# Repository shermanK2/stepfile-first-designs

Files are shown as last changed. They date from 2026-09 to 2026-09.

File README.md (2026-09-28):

# First designs — STEP files

Wing and tail designs for small RC aircraft, exported as STEP files for manufacturing.
Each design iteration is kept in its own folder so earlier versions stay available and
comparable.

## Layout

```
<aircraft>/
├── README.md                    aircraft reference data (published specs, measurements)
└── v<N>-<YYYY-MM-DD>/           one folder per design iteration
    ├── README.md                design notes: parameters, dimensions, results, status
    ├── wing/                    main wing
    ├── tail/                    horizontal tail (hstab) and fin (vstab)
    └── assembly/                full aircraft, for fit checks only — not for cutting
templates/
└── design-notes.md              copy this into each new iteration folder
```

## Iterations

| Aircraft | Version | Date | Summary | Status |
|---|---|---|---|---|
| [Kavan Beta 1400](kavan-beta-1400/) | [v1](kavan-beta-1400/v1-2026-09-28/) | 2026-09-28 | Trapezoidal wing (AR 8, taper 0.6, 3° dihedral), conventional tail | Designed, not built |

## Conventions

- **Units:** every STEP file is in **millimetres**.
- **File names:** `<part>_mm.step`, e.g. `wing_mm.step`, `hstab_mm.step`, `fin_mm.step`.
- **Versions are never edited after they are sent to manufacturing.** A change means a new
  folder (`v2-…`), not an overwrite. Small fixes before anything is sent can stay in the
  same version; note them in its README.
- **Coordinates:** x = chordwise (aft positive), y = spanwise, z = up. Separate part files
  are in the part's own frame; the assembly file is in aircraft coordinates.

## Adding a new iteration

1. Create `<aircraft>/v<N>-<YYYY-MM-DD>/` with `wing/`, `tail/` and `assembly/` inside.
2. Copy the new STEP files in. Check each one opens at the expected size in mm.
3. Copy [`templates/design-notes.md`](templates/design-notes.md) to the new folder as
   `README.md` and fill it in, including **what changed since the previous version**.
4. Add a row to the **Iterations** table above.
5. Commit with a message like `Kavan Beta 1400 v2: <what changed>`.

## Tooling

The designs are generated with AeroForge (IDEAL Lab, ETH Zürich). The design scripts
live with the lab's AeroForge repository and are not included here.

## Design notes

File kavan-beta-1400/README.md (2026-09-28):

# Kavan Beta 1400

EPO-foam trainer / motor glider with aileron, elevator, rudder and motor control. New
wings and tails are designed to fit its existing fuselage.

## Published specifications

| | Value |
|---|---|
| Wingspan | 1400 mm |
| Length | 966 mm |
| Wing area | 24.5 dm² (0.245 m²) → aspect ratio 8.0, mean chord 175 mm |
| Flying weight | 700–770 g → wing loading ≈ 2.9–3.1 kg/m² |
| Motor / prop | C2814-1400 brushless, 7×6" folding prop |
| ESC | 20 A |
| Battery | 3S 11.1 V LiPo, 1600 mAh (up to 2200 mAh) |
| Servos | 4 × GO-09 (9 g) |

Sources: [kavanrc.com](https://www.kavanrc.com/en/item/kavan-beta-1400-rtf-red-151588),
[air-rc.com](https://www.air-rc.com/aircraft/kavan_beta-1400_kav02-8085).

## Not published — to measure on the real fuselage

| | Value |
|---|---|
| Fuselage max width / height | _to measure_ |
| Nose → wing root leading edge | _to measure_ |
| Nose → tailplane root leading edge | _to measure_ |
| Nose → fin root leading edge | _to measure_ |
| Wing mount / saddle shape | _to measure_ |
| Stock CG position | _to measure_ |

Fill these in once measured; later versions should use them instead of placeholders.

## Versions

| Version | Date | Summary |
|---|---|---|
| [v1](v1-2026-09-28/) | 2026-09-28 | First trapezoidal wing and conventional tail |

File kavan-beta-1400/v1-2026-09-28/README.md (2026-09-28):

# Kavan Beta 1400 — v1 (2026-09-28)

First trapezoidal wing and conventional tail designed around the Kavan Beta 1400 fuselage.

**Status:** designed, not yet built or flown.
**Changes from previous version:** none — first version.

## Files

| File | Part | Size (x × y × z, mm) |
|---|---|---|
| [`wing/wing_mm.step`](wing/wing_mm.step) | Main wing, one piece tip to tip | 218.8 × 1400.0 × 56.3 |
| [`tail/hstab_mm.step`](tail/hstab_mm.step) | Horizontal tail | 131.3 × 420.0 × 15.8 |
| [`tail/fin_mm.step`](tail/fin_mm.step) | Fin (exported lying flat, height along y) | 168.9 × 190.0 × 20.3 |
| [`assembly/aircraft_fitcheck_mm.step`](assembly/aircraft_fitcheck_mm.step) | Full aircraft — fit check only | 1034.7 × 1400.0 × 303.5 |

All files are in millimetres.

## Design parameters

| Part | Span | Aspect ratio | Taper | Thickness | Sweep | Dihedral | Airfoil |
|---|---|---|---|---|---|---|---|
| Wing | 1400 mm | 8.0 | 0.6 | 12 % | 0° | 3° | NACA 2412 |
| Horizontal tail | 420 mm | 4.0 | 0.6 | 10 % | 0° | 0° | NACA 0012 |
| Fin | 190 mm (height) | 1.5 | 0.5 | 10 % | 0° | — | NACA 0012 |

## Derived dimensions

| | Wing | Horizontal tail | Fin |
|---|---|---|---|
| Area | 0.2450 m² | 0.0441 m² | 0.0241 m² |
| Mean chord | 175.0 mm | 105.0 mm | 126.7 mm |
| Root chord | 218.8 mm | 131.3 mm | 168.9 mm |
| Tip chord | 131.3 mm | 78.8 mm | 84.4 mm |
| Mean aerodynamic chord (MAC) | 178.6 mm | | |

Tail volume coefficients (tail arm 599 mm): horizontal **0.62**, vertical **0.042** —
both in the usual trainer range (0.45–0.65 and 0.035–0.05).

## Fuselage and placement used

| | Value | Source |
|---|---|---|
| Fuselage length | 966 mm | Published |
| Fuselage width × height | 150 × 140 mm | **Placeholder** |
| Wing ¼-root-chord position | 30 % of length (290 mm from nose) | **Placeholder** |
| Tail ¼-root-chord position | 92 % of length (889 mm from nose) | **Placeholder** |

The fit-check assembly uses these placeholders, so it is approximate until they are measured.

## Predicted performance (AeroForge handbook models)

| | Value | Notes |
|---|---|---|
| Flying weight used | 0.737 kg | Tuned to the published 700–770 g |
| Stall speed | 6.2 m/s | Fixed CLmax 1.3 — rough |
| Best L/D | 13.0 | At ~7.8 m/s |
| Spar safety factor | 6.4 | 8/6 mm carbon tube, 3 g, tube carries all load |
| Wing tip deflection | 25 mm | At 3 g |

Conditions: cruise 13 m/s, altitude 450 m.

## Manufacturing notes

- **Wing is one solid piece** (1.4 m) with **no spar slot**. Decide whether to split it at
  the root.
- **Spar:** planned as an 8 mm OD / 6 mm ID carbon tube at the root quarter-chord. A single
  straight tube will exit the wing near the tips because of the 3° dihedral (tip is ~16 mm
  thick but ~37 mm higher) — use **two half-spars joined with a dihedral brace**.
- **Fin** is exported lying flat; it is the vertical fin.
- **Incidence** is not included in the geometry; set it when mounting.
- **Balance** at 25–30 % MAC: **45–54 mm behind the wing leading edge**, nose-heavy end
  first.
- The assembly file contains ~15 separate bodies and is for reference only.

## Open items for v2

- [ ] Measure fuselage width, height and the wing and tail mount positions.
- [ ] Weigh the real components and update the mass.
- [ ] Decide wing split and spar joint.
- [ ] Record build and flight results here.

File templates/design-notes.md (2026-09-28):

# <Aircraft> — v<N> (<YYYY-MM-DD>)

<One sentence: what this version is.>

**Status:** designed / sent to manufacturing / built / flown
**Changes from previous version:** <what changed and why, e.g. "AR 8 → 9 to lower stall speed">

## Files

| File | Part | Size (x × y × z, mm) |
|---|---|---|
| `wing/wing_mm.step` | Main wing | |
| `tail/hstab_mm.step` | Horizontal tail | |
| `tail/fin_mm.step` | Fin | |
| `assembly/aircraft_fitcheck_mm.step` | Full aircraft — fit check only | |

## Design parameters

| Part | Span | Aspect ratio | Taper | Thickness | Sweep | Dihedral | Airfoil |
|---|---|---|---|---|---|---|---|
| Wing | | | | | | | |
| Horizontal tail | | | | | | | |
| Fin | | | | | | — | |

## Derived dimensions

| | Wing | Horizontal tail | Fin |
|---|---|---|---|
| Area | | | |
| Mean chord | | | |
| Root chord | | | |
| Tip chord | | | |
| MAC | | | |

Tail volume coefficients: horizontal ___, vertical ___

## Fuselage and placement used

| | Value | Source (published / measured / placeholder) |
|---|---|---|
| Fuselage length | | |
| Fuselage width × height | | |
| Wing ¼-root-chord position | | |
| Tail ¼-root-chord position | | |

## Predicted performance

| | Value | Notes |
|---|---|---|
| Flying weight used | | |
| Stall speed | | |
| Best L/D | | |
| Spar safety factor | | |
| Wing tip deflection | | |

## Manufacturing notes

-

## Build and flight results

| Date | What | Result |
|---|---|---|
| | | |

## Open items for next version

- [ ]

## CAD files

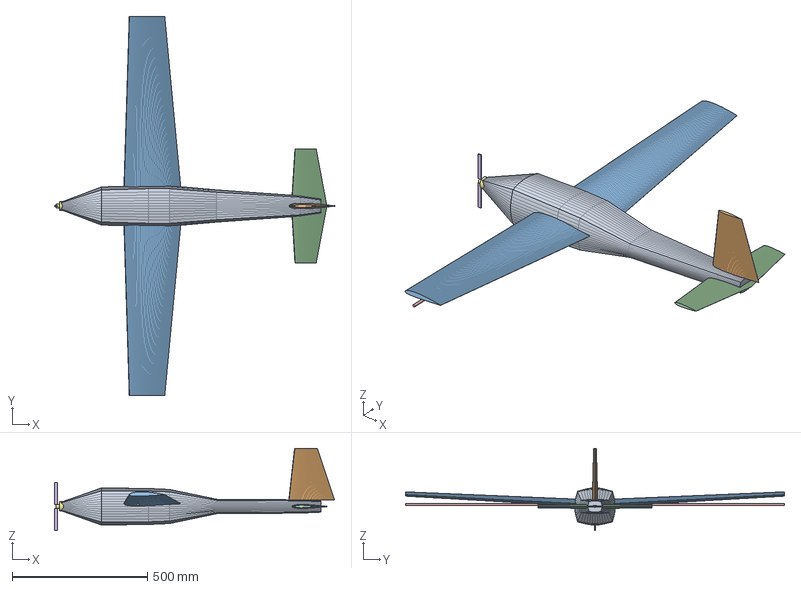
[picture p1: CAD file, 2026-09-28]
kavan-beta-1400/v1-2026-09-28/assembly/aircraft_fitcheck_mm.step
1034.7 x 1400.0 x 303.5 mm

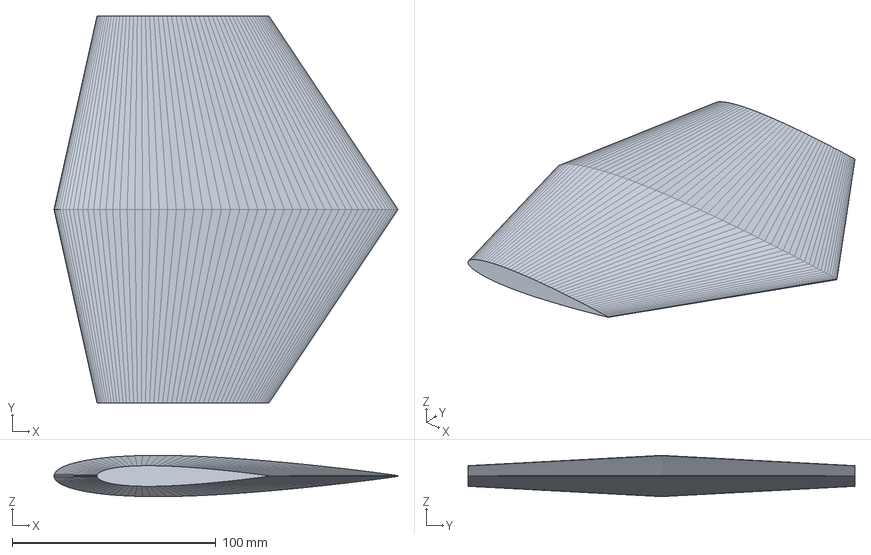
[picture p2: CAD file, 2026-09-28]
kavan-beta-1400/v1-2026-09-28/tail/fin_mm.step
168.9 x 190.0 x 20.3 mm

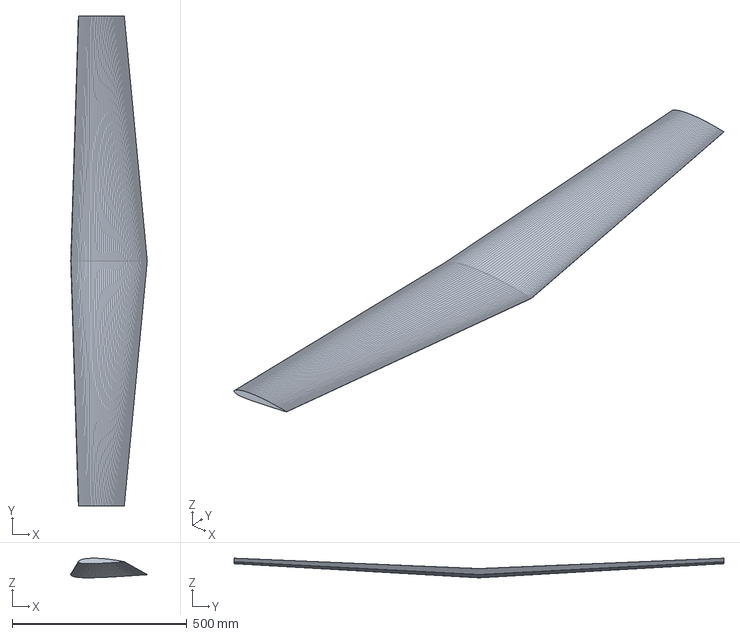
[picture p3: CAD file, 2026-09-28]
kavan-beta-1400/v1-2026-09-28/wing/wing_mm.step
218.8 x 1400.0 x 56.3 mm

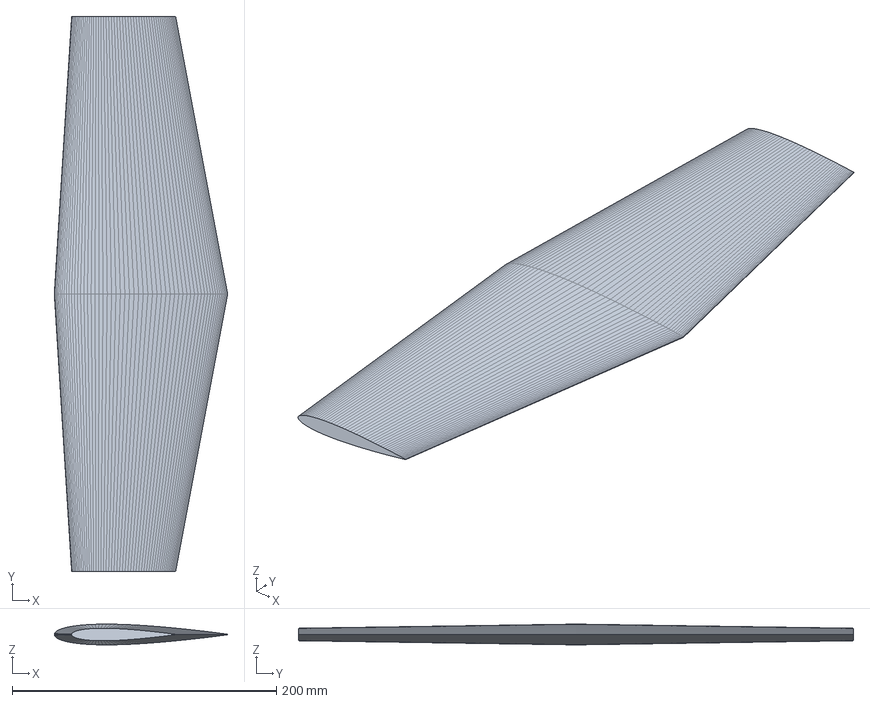
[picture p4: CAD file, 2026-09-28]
kavan-beta-1400/v1-2026-09-28/tail/hstab_mm.step
131.2 x 420.0 x 15.8 mm

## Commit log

2026-09-28 First Kavan Beta 1400 designs: wing, tailplane, fin and fit-check STEP files (mm)
    [aircraft_fitcheck_mm.step, fin_mm.step, hstab_mm.step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]
2026-09-28 Organise designs by aircraft and version: wing, tail, assembly
    [aircraft_fitcheck_mm.step, fin_mm.step, hstab_mm.step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]
